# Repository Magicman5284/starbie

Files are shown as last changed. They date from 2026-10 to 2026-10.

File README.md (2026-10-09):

Starbie

Starbie is a virtual pet powered by a Seeed XIAO ESP32-C3, with an OLED display, motion sensing, and temperature/humidity readings. It also works as a Bluetooth macropad.

Features

Virtual pet with Joy, Energy, and Fullness stats

Motion-based interactions and pet activities

Bluetooth shortcuts for Copy, Paste, Cut, Undo, and Screenshot

Switch between pet and macropad modes using D2

Hardware: XIAO ESP32-C3, OLED, MPU6050, DHT11, and six buttons.

Libraries: Adafruit SSD1306, Adafruit GFX, MPU6050, DHT, and a compatible BLE Keyboard library.



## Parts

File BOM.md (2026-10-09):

# Starbie – bill of materials

<!-- Generated by Half Life from project cmuvlfubk01nb01pyzaf8hww4. Edits here are overwritten on the next sync. -->
<!-- Generated: 2026-10-09T00:57:36.305Z -->

> [!NOTE]
> This parts list is mirrored from [Half Life](https://halflife.hackclub.com). Editing it here will not change the platform's copy, and the next sync overwrites this file.

| Week | Tier | Parts funding |
| --- | --- | --- |
| Week 1 | Tier 1 | $30.00 |

| Part | What it's for | Qty | Unit | Total | Vendor |
| --- | --- | --- | --- | --- | --- |
| [PCB](https://cart.jlcpcb.com/quote) | where components are mounted | 1 | $11.19 | $11.19 | [JLCPCB](https://cart.jlcpcb.com/quote) |
| [Keyboard switches](https://www.aliexpress.us/item/3256809144133324.html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) | button inputs | 1 | $3.80 | $3.80 | [Aliexpress](https://www.aliexpress.us/item/3256809144133324.html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) |
| [Keycaps](https://www.aliexpress.us/item/3256812392832257.html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) | to cover the switches | 1 | $2.50 | $2.50 | [Aliexpress](https://www.aliexpress.us/item/3256812392832257.html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) |
| [DHT11](https://www.aliexpress.us/item/3256808632582299.html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) | environmental sensing | 1 | $1.89 | $1.89 | [Aliexpress](https://www.aliexpress.us/item/3256808632582299.html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) |
| [MPU6050](https://www.aliexpress.us/item/3256809871479525.html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) | Accelerometer & Gyroscope | 1 | $2.10 | $2.10 | [aliexpress](https://www.aliexpress.us/item/3256809871479525.html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) |
| [OLED screen](https://www.aliexpress.us/item/3256804169233174.html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) | to display the starby | 1 | $2.21 | $2.21 | [aliexpress](https://www.aliexpress.us/item/3256804169233174.html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) |
| [XIAO ESP32-C3](https://www.aliexpress.us/item/3256809899117724.html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) | to run the program | 1 | $8.83 | $8.83 | [Aliexpress](https://www.aliexpress.us/item/3256809899117724.html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) |
| **Parts subtotal** | — | — | — | **$32.52** | — |
| **Tax & shipping** | — | — | — | **$0.00** | — |
| **Total** | — | — | — | **$32.52** | — |

**$2.52 over the tier's funding.** Every tier gives a fixed amount for parts, so this needs cutting back or a higher tier.

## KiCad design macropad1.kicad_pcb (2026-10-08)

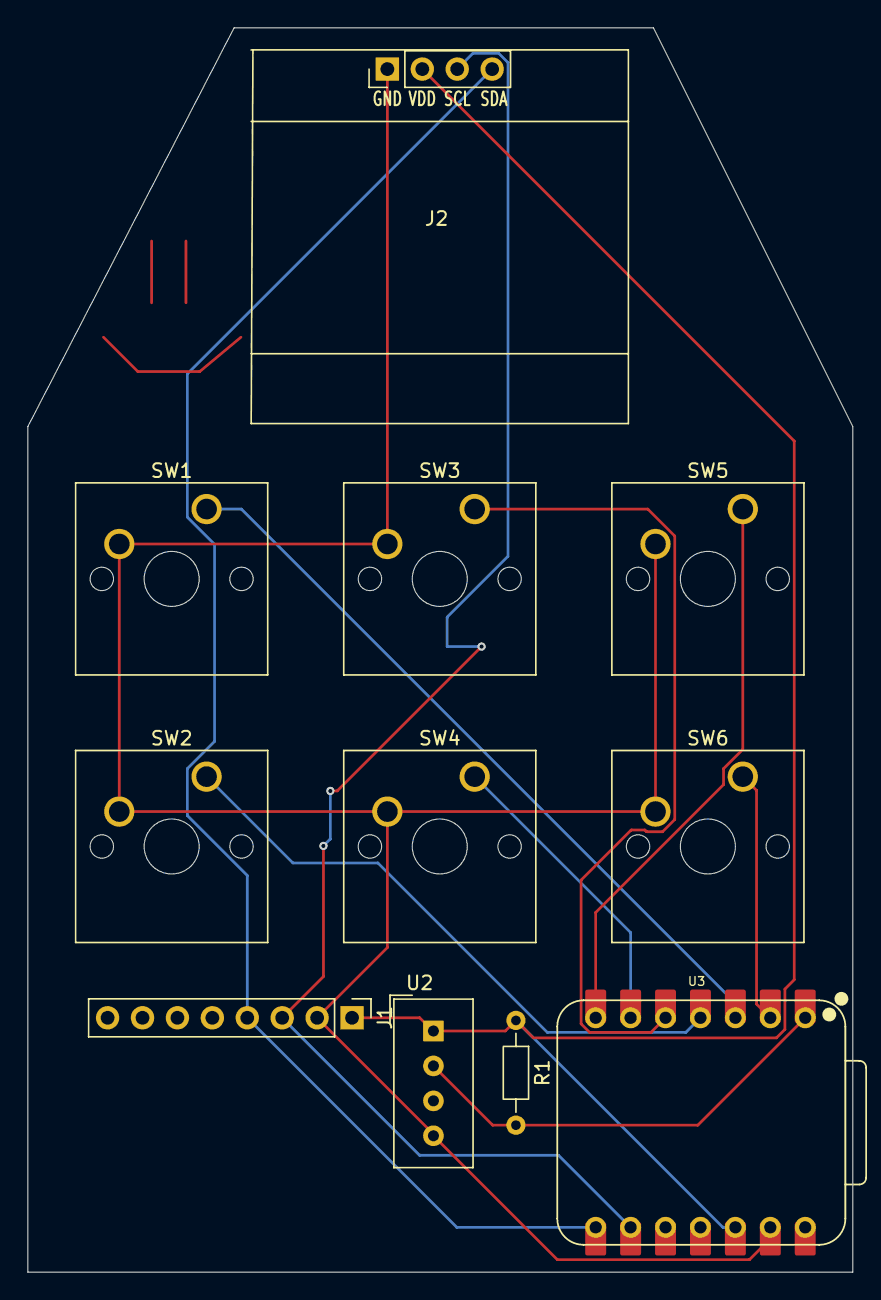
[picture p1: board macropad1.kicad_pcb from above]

Board: 2 copper layers, 60.0 x 90.5 mm, 11 parts (0 on the bottom side), 11 nets.

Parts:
J1: Conn_01x08_Pin; PinHeader_1x08_P2.54mm_Vertical
J2: Conn_01x04_Pin; Display_128x64_096_I2C
R1: 10k; R_Axial_DIN0204_L3.6mm_D1.6mm_P7.62mm_Horizontal
SW1, SW2, SW3, SW4, SW5, SW6: SW_Push; SW_Cherry_MX_1.00u_PCB
U2: DHT11; Aosong_DHT11_5.5x12.0_P2.54mm
U3: XIAO-Add-On; XIAO-ESP32-C3-DIP

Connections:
+3.3V: J1.1, J2.2, R1.1, U2.1 (VDD), U3.12 (3V3_OUT)
/DHT11 DATA: R1.2, U2.2 (DATA), U3.1 (D0)
/GPIO1: SW6.1, U3.2 (D1)
/GPIO2: SW1.1, U3.3 (D2)
/GPIO3: SW2.1, U3.4 (D3)
/GPIO4: SW3.1, U3.5 (D4)
/GPIO5: SW4.1, U3.6 (D5)
/GPIO6: SW5.1, U3.7 (D6)
/SCL: J1.3, J2.3, U3.9 (D8)
/SDA: J1.4, J2.4, U3.8 (D7)
GND: J1.2, J2.1, SW1.2, SW2.2, SW3.2, SW4.2, SW5.2, SW6.2, U2.4 (GND), U3.13 (GND)

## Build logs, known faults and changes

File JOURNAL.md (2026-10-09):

# Starbie – devlog

<!-- Generated by Half Life from project cmuvlfubk01nb01pyzaf8hww4. Edits here are overwritten on the next sync. -->
<!-- Generated: 2026-10-09T01:02:13.699Z -->

> [!NOTE]
> This devlog is mirrored from [Half Life](https://halflife.hackclub.com). Editing it here will not change the platform's copy, and the next sync overwrites this file.

> A tiny motion-controlled digital pet, basically a desktop Tamagotchi. Totally not a Starboy.

| Week | Tier | Hours logged | Entries |
| --- | --- | --- | --- |
| Week 1 | Tier 1 | 12.15h | 5 |

## Contents

1. [2026-10-05 – Work session](#2026-10-05-work-session)
2. [2026-10-06 – Work session](#2026-10-06-work-session)
3. [2026-10-06 – I just finished up designing my PCB and exported the files. It took me way longer than it should have to figure out how to add an image on to the PCB, but I eventually figured it out. After that, I ex](#2026-10-06-i-just-finished-up-designing-my-pcb-and-exported-)
4. [2026-10-08 – In this session I completely redesigned my PCB. I created it more like a macro pad with six buttons instead of the 2 that were in the first one I designed. This was a bit easier than the first time be](#2026-10-08-in-this-session-i-completely-redesigned-my-pcb-i-)
5. [2026-10-08 – This session I did a lot of work in the Arduino ide trying to alter the code for starbie. I tried to make it so that I can toggle it between it acting as a pet and acting as a macropad. In the future,](#2026-10-08-this-session-i-did-a-lot-of-work-in-the-arduino-i)

## Design

### 2026-10-05 – Work session

**0.73h**

[Timelapse](https://lookout.hackclub.com/api/media/c5e8a572-05f9-4baf-ba6c-8380ce65a804/video.mp4)

### 2026-10-06 – Work session

**1.92h**

[Timelapse](https://lookout.hackclub.com/api/media/7532431c-2f96-4bbc-b52b-e5117d1896b4/video.mp4)

### 2026-10-06 – I just finished up designing my PCB and exported the files. It took me way longer than it should have to figure out how to add an image on to the PCB, but I eventually figured it out. After that, I ex

**1h**

I just finished up designing my PCB and exported the files. It took me way longer than it should have to figure out how to add an image on to the PCB, but I eventually figured it out. After that, I exported all of the design and manufacturing files and put them in my project's GitHub. Now I just need to work on the firmware. I am currently considering redesigning the project to have more buttons.





### 2026-10-08 – In this session I completely redesigned my PCB. I created it more like a macro pad with six buttons instead of the 2 that were in the first one I designed. This was a bit easier than the first time be

**5h**

In this session I completely redesigned my PCB. I created it more like a macro pad with six buttons instead of the 2 that were in the first one I designed. This was a bit easier than the first time because I already had a decent idea of what I was doing, but I still had a few hiccups that ended up taking a while to resolve. Now I need to shift my focus from hardware to software and creating the Bill of materials.











### 2026-10-08 – This session I did a lot of work in the Arduino ide trying to alter the code for starbie. I tried to make it so that I can toggle it between it acting as a pet and acting as a macropad. In the future,

**3.5h**

This session I did a lot of work in the Arduino ide trying to alter the code for starbie. I tried to make it so that I can toggle it between it acting as a pet and acting as a macropad. In the future, I think it would be great to have these functions seamlessly integrated so that the pad can interact and react with the macropad.

I also spent some time in the github, adding files and writing the ReadMe. After this I worked on the Bill of materials.









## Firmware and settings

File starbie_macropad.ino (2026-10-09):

/*
  STARBIE + BLUETOOTH MACROPAD
  Board: Seeed XIAO ESP32-C3

  D0 = DHT11 data
  D1 = Button 1
  D2 = Mode toggle
  D3 = Button 3
  D4 = Button 4
  D5 = Button 5
  D6 = Button 6
  D7 = OLED SDA
  D8 = OLED SCL

  Buttons connect their GPIO pin to GND when pressed.

  STARBIE MODE:
    D1 = Open/confirm tilt menu
    D2 = Switch to Macropad mode
    D3 = Show/hide stats
    D4 = Nap
    D5 = Play
    D6 = Feed

  MACROPAD MODE (Windows):
    D1 = Copy
    D2 = Return to Starbie mode
    D3 = Paste
    D4 = Cut
    D5 = Undo
    D6 = Screenshot (Win + Shift + S)
*/

#define USE_NIMBLE
#include <Wire.h>
#include <Adafruit_GFX.h>
#include <Adafruit_SSD1306.h>
#include <Adafruit_MPU6050.h>
#include <Adafruit_Sensor.h>
#include <DHT.h>
#include <Preferences.h>
#include <BleKeyboard.h>
#include <math.h>

// -------------------- PIN SETTINGS --------------------

const int SDA_PIN = 20;       // XIAO D7
const int SCL_PIN = 8;        // XIAO D8
const int DHT_PIN = 2;        // XIAO D0

const int BUTTON_D1 = 3;
const int BUTTON_D2 = 4;
const int BUTTON_D3 = 5;
const int BUTTON_D4 = 6;
const int BUTTON_D5 = 7;
const int BUTTON_D6 = 21;

const int BUTTON_PINS[6] = {
  BUTTON_D1, BUTTON_D2, BUTTON_D3,
  BUTTON_D4, BUTTON_D5, BUTTON_D6
};

const uint8_t OLED_ADDRESS = 0x3C;
const uint8_t MPU_ADDRESS = 0x68;

const bool USE_DHT11 = true;
const bool RESET_SAVED_PET_ON_BOOT = false;

// -------------------- DEVICES --------------------

const int SCREEN_WIDTH = 128;
const int SCREEN_HEIGHT = 64;

Adafruit_SSD1306 display(
  SCREEN_WIDTH, SCREEN_HEIGHT, &Wire, -1
);

Adafruit_MPU6050 mpu;
DHT dht(DHT_PIN, DHT11);
Preferences preferences;

BleKeyboard bleKeyboard(
  "Starbie Macropad", "Starbie", 100
);

// -------------------- PET SETTINGS --------------------

const int PET_WIDTH = 32;
const int PET_HEIGHT = 32;

const int STARTING_JOY = 70;
const int STARTING_ENERGY = 75;
const int STARTING_FULLNESS = 65;

const uint32_t WALK_PIXEL_MS = 70;
const uint32_t PRE_JUMP_MS = 230;
const uint32_t JUMP_MS = 430;
const int JUMP_HEIGHT = 16;

const uint32_t NAP_DURATION_MS = 48000;
const uint32_t HEART_DURATION_MS = 1600;
const uint32_t PLAY_LAP_MS = 800;
const int PLAY_LAP_COUNT = 2;

const uint32_t SHAKE_COOLDOWN_MS = 650;
const float SHAKE_THRESHOLD = 7.0f;
const float GRAVITY = 9.80665f;

const float MENU_TILT_LIMIT = 6.0f;
const float MENU_DEADZONE = 0.8f;
const float MENU_X_DIRECTION = 1.0f;
const float MENU_Y_DIRECTION = -1.0f;
const bool SWAP_MPU_AXES = false;

const uint32_t BUTTON_DEBOUNCE_MS = 30;
const uint32_t MPU_INTERVAL_MS = 30;
const uint32_t DHT_INTERVAL_MS = 2200;

// -------------------- PET DATA --------------------

struct PetState {
  int joy;
  int energy;
  int fullness;
};

PetState pet = {
  STARTING_JOY, STARTING_ENERGY, STARTING_FULLNESS
};

struct ButtonState {
  bool stableState;
  bool lastRawState;
  uint32_t lastChangedAt;
};

ButtonState buttons[6];

enum DeviceMode {
  STARBIE_MODE,
  MACROPAD_MODE
};

enum ScreenView {
  PET_VIEW,
  MENU_VIEW,
  STATS_VIEW
};

DeviceMode currentMode = STARBIE_MODE;
ScreenView currentView = PET_VIEW;

bool mpuFound = false;
bool dhtFound = false;

float accelX = 0;
float accelY = 0;
float accelZ = GRAVITY;

float temperatureC = NAN;
float humidity = NAN;

float menuBallX = 64;
float menuBallY = 32;

float menuCenterX = 0;
float menuCenterY = 0;

int selectedMenuItem = -1;
int nappingPetX = 0;

uint32_t lastMpuReadAt = 0;
uint32_t lastDhtReadAt = 0;
uint32_t lastShakeAt = 0;

uint32_t shakeAnimationEndsAt = 0;
uint32_t jumpStartedAt = 0;
uint32_t nappingUntil = 0;
uint32_t heartsUntil = 0;
uint32_t playStartedAt = 0;

// -------------------- PET SPRITE --------------------

const uint8_t PROGMEM PET_SPRITE[] = {
  0x00,0x00,0x00,0x00,
  0x00,0x00,0x00,0x00,
  0x00,0x00,0x00,0x00,
  0x00,0x00,0x00,0x00,
  0x00,0x00,0x00,0x00,
  0x00,0x00,0x00,0x00,
  0x00,0x70,0x0a,0x00,
  0x00,0xf8,0x1f,0x00,
  0x00,0x8c,0x3f,0x80,
  0x00,0x43,0xff,0x00,
  0x00,0x43,0xff,0x00,
  0x00,0x30,0x7e,0x00,
  0x00,0x98,0x01,0x00,
  0x01,0x98,0x01,0x80,
  0x03,0x00,0x10,0xc0,
  0x03,0x04,0x00,0xc0,
  0x01,0x8b,0x01,0x80,
  0x01,0xcb,0x03,0x80,
  0x03,0xc0,0x03,0xc0,
  0x03,0xc0,0x03,0xc0,
  0x01,0xc0,0x03,0x80,
  0x01,0x80,0x01,0x80,
  0x00,0x60,0x06,0x00,
  0x00,0x3f,0xfc,0x00,
  0x00,0x7f,0xfe,0x00,
  0x00,0x70,0x0e,0x00,
  0x00,0x00,0x00,0x00,
  0x00,0x00,0x00,0x00,
  0x00,0x00,0x00,0x00,
  0x00,0x00,0x00,0x00,
  0x00,0x00,0x00,0x00,
  0x00,0x00,0x00,0x00
};

// -------------------- MENU ACTIONS --------------------

enum PetReaction {
  NAP_REACTION,
  RUN_REACTION,
  JUMP_REACTION,
  HEART_REACTION
};

struct MenuItem {
  const char *label;
  int joy;
  int energy;
  int fullness;
  PetReaction reaction;
};

const MenuItem MENU_ITEMS[] = {
  {"NAP",  1, 18, -4, NAP_REACTION},
  {"PLAY", 12, -9, -5, RUN_REACTION},
  {"FEED", 3, 2, 18, JUMP_REACTION},
  {"PET",  7, 0, 0, HEART_REACTION}
};

const int MENU_X[] = {64, 108, 64, 20};
const int MENU_Y[] = {12, 32, 53, 32};

// -------------------- GENERAL HELPERS --------------------

int clampStat(int value) {
  return constrain(value, 0, 100);
}

void changePet(int joy, int energy, int fullness) {
  pet.joy = clampStat(pet.joy + joy);
  pet.energy = clampStat(pet.energy + energy);
  pet.fullness = clampStat(pet.fullness + fullness);
}

void savePet() {
  preferences.putInt("joy", pet.joy);
  preferences.putInt("energy", pet.energy);
  preferences.putInt("full", pet.fullness);
}

void loadPet() {
  preferences.begin("starbie", false);

  if (RESET_SAVED_PET_ON_BOOT) {
    preferences.clear();
  }

  pet.joy = preferences.getInt("joy", STARTING_JOY);
  pet.energy = preferences.getInt("energy", STARTING_ENERGY);
  pet.fullness = preferences.getInt("full", STARTING_FULLNESS);
}

bool wasPressed(int index) {
  bool raw = digitalRead(BUTTON_PINS[index]);
  uint32_t now = millis();

  if (raw != buttons[index].lastRawState) {
    buttons[index].lastRawState = raw;
    buttons[index].lastChangedAt = now;
  }

  if (raw != buttons[index].stableState &&
      now - buttons[index].lastChangedAt >=
      BUTTON_DEBOUNCE_MS) {
    buttons[index].stableState = raw;
    return buttons[index].stableState == LOW;
  }

  return false;
}

bool isNapping() {
  return nappingUntil != 0 && millis() < nappingUntil;
}

bool isPlaying() {
  return playStartedAt != 0 &&
         millis() - playStartedAt <
         PLAY_LAP_MS * PLAY_LAP_COUNT;
}

int walkingX(uint32_t now) {
  const int farthest = SCREEN_WIDTH - PET_WIDTH;
  const uint32_t roundTrip = farthest * 2UL;
  const uint32_t step = (now / WALK_PIXEL_MS) % roundTrip;

  return step <= farthest ? step : roundTrip - step;
}

int runningX(uint32_t now) {
  const int farthest = SCREEN_WIDTH - PET_WIDTH;
  float progress = float((now - playStartedAt) % PLAY_LAP_MS)
                   / PLAY_LAP_MS;

  if (progress < 0.5f) {
    return int(progress * 2.0f * farthest);
  }

  return int((1.0f - progress) * 2.0f * farthest);
}

// -------------------- SENSOR UPDATES --------------------

void updateMPU() {
  if (!mpuFound ||
      millis() - lastMpuReadAt < MPU_INTERVAL_MS) {
    return;
  }

  lastMpuReadAt = millis();

  sensors_event_t acceleration;
  sensors_event_t gyro;
  sensors_event_t sensorTemperature;

  mpu.getEvent(
    &acceleration, &gyro, &sensorTemperature
  );

  accelX = acceleration.acceleration.x;
  accelY = acceleration.acceleration.y;
  accelZ = acceleration.acceleration.z;
}

void updateDHT() {
  if (!dhtFound ||
      millis() - lastDhtReadAt < DHT_INTERVAL_MS) {
    return;
  }

  lastDhtReadAt = millis();

  float newHumidity = dht.readHumidity();
  float newTemperature = dht.readTemperature();

  if (!isnan(newHumidity)) {
    humidity = newHumidity;
  }

  if (!isnan(newTemperature)) {
    temperatureC = newTemperature;
  }
}

// -------------------- PET ACTIONS --------------------

void doNap() {
  uint32_t now = millis();

  nappingPetX = walkingX(now);
  nappingUntil = now + NAP_DURATION_MS;

  jumpStartedAt = 0;
  playStartedAt = 0;
  heartsUntil = 0;

  changePet(1, 18, -4);
  savePet();
}

void doPlay() {
  playStartedAt = millis();
  jumpStartedAt = 0;
  nappingUntil = 0;
  heartsUntil = playStartedAt + PLAY_LAP_MS * PLAY_LAP_COUNT;

  changePet(12, -9, -5);
  savePet();
}

void doFeed() {
  uint32_t now = millis();

  nappingUntil = 0;
  playStartedAt = 0;
  jumpStartedAt = now;
  heartsUntil = 0;

  changePet(3, 2, 18);
  savePet();
}

void doPet() {
  uint32_t now = millis();

  nappingUntil = 0;
  playStartedAt = 0;
  jumpStartedAt = now;
  heartsUntil = now + HEART_DURATION_MS;

  changePet(7, 0, 0);
  savePet();
}

void updatePetTimers() {
  uint32_t now = millis();

  if (nappingUntil != 0 && now >= nappingUntil) {
    nappingUntil = 0;
  }

  if (playStartedAt != 0 && !isPlaying()) {
    playStartedAt = 0;
  }

  if (jumpStartedAt != 0 &&
      now - jumpStartedAt >= PRE_JUMP_MS + JUMP_MS) {
    jumpStartedAt = 0;
  }
}

void checkForShake() {
  if (!mpuFound || currentView != PET_VIEW) {
    return;
  }

  float magnitude = sqrtf(
    accelX * accelX +
    accelY * accelY +
    accelZ * accelZ
  );

  uint32_t now = millis();

  if (fabsf(magnitude - GRAVITY) >= SHAKE_THRESHOLD &&
      now - lastShakeAt >= SHAKE_COOLDOWN_MS) {
    lastShakeAt = now;
    nappingUntil = 0;
    shakeAnimationEndsAt = now + 350;

    changePet(5, -2, -1);
    savePet();
  }
}

// -------------------- RADIAL MENU --------------------

void openMenu() {
  currentView = MENU_VIEW;
  selectedMenuItem = -1;

  menuBallX = 64;
  menuBallY = 32;

  menuCenterX = accelX;
  menuCenterY = accelY;
}

void updateMenuBall() {
  if (!mpuFound) {
    selectedMenuItem = -1;
    return;
  }

  float xTilt = accelX - menuCenterX;
  float yTilt = accelY - menuCenterY;

  if (SWAP_MPU_AXES) {
    float temp = xTilt;
    xTilt = yTilt;
    yTilt = temp;
  }

  xTilt = constrain(
    xTilt * MENU_X_DIRECTION,
    -MENU_TILT_LIMIT, MENU_TILT_LIMIT
  );

  yTilt = constrain(
    yTilt * MENU_Y_DIRECTION,
    -MENU_TILT_LIMIT, MENU_TILT_LIMIT
  );

  float targetX = 64 + (xTilt / MENU_TILT_LIMIT) * 37;
  float targetY = 32 + (yTilt / MENU_TILT_LIMIT) * 22;

  menuBallX += (targetX - menuBallX) * 0.20f;
  menuBallY += (targetY - menuBallY) * 0.20f;

  if (fabsf(xTilt) < MENU_DEADZONE &&
      fabsf(yTilt) < MENU_DEADZONE) {
    selectedMenuItem = -1;
  } else if (fabsf(xTilt) > fabsf(yTilt)) {
    selectedMenuItem = xTilt > 0 ? 1 : 3;
  } else {
    selectedMenuItem = yTilt > 0 ? 2 : 0;
  }
}

void chooseMenuItem() {
  if (selectedMenuItem < 0) {
    return;
  }

  const MenuItem &item = MENU_ITEMS[selectedMenuItem];

  if (item.reaction == NAP_REACTION) {
    doNap();
  } else if (item.reaction == RUN_REACTION) {
    doPlay();
  } else if (item.reaction == JUMP_REACTION) {
    doFeed();
  } else {
    doPet();
  }

  currentView = PET_VIEW;
}

// -------------------- BLUETOOTH MACROPAD --------------------

void sendShortcut(uint8_t modifier, char key) {
  if (!bleKeyboard.isConnected()) {
    Serial.println("Macropad: Bluetooth not connected.");
    return;
  }

  bleKeyboard.press(modifier);
  bleKeyboard.press(key);

  delay(40);
  bleKeyboard.releaseAll();
  delay(30);
}

void sendScreenshotShortcut() {
  if (!bleKeyboard.isConnected()) {
    Serial.println("Macropad: Bluetooth not connected.");
    return;
  }

  // Windows + Shift + S
  bleKeyboard.press(KEY_LEFT_GUI);
  bleKeyboard.press(KEY_LEFT_SHIFT);
  bleKeyboard.press('s');

  delay(60);
  bleKeyboard.releaseAll();
  delay(30);
}

void handleMacropadButtons() {
  if (wasPressed(0)) {
    sendShortcut(KEY_LEFT_CTRL, 'c');  // D1: Copy
  }

  if (wasPressed(2)) {
    sendShortcut(KEY_LEFT_CTRL, 'v');  // D3: Paste
  }

  if (wasPressed(3)) {
    sendShortcut(KEY_LEFT_CTRL, 'x');  // D4: Cut
  }

  if (wasPressed(4)) {
    sendShortcut(KEY_LEFT_CTRL, 'z');  // D5: Undo
  }

  if (wasPressed(5)) {
    sendScreenshotShortcut();          // D6: Screenshot
  }
}

// -------------------- MODE AND BUTTON HANDLING --------------------

void toggleMode() {
  if (currentMode == STARBIE_MODE) {
    currentMode = MACROPAD_MODE;
    currentView = PET_VIEW;
    Serial.println("Mode: MACROPAD");
  } else {
    currentMode = STARBIE_MODE;
    currentView = PET_VIEW;
    Serial.println("Mode: STARBIE");
  }
}

void handleButtons() {
  // D2 always changes modes, regardless of the current mode.
  if (wasPressed(1)) {
    toggleMode();
    return;
  }

  if (currentMode == MACROPAD_MODE) {
    handleMacropadButtons();
    return;
  }

  // Starbie mode:
  if (wasPressed(0)) {
    if (currentView == MENU_VIEW) {
      chooseMenuItem();
    } else {
      openMenu();
    }
  }

  if (wasPressed(2)) {
    currentView = currentView == STATS_VIEW
                    ? PET_VIEW
                    : STATS_VIEW;
  }

  // Three extra direct-action buttons.
  if (wasPressed(3)) {
    doNap();
    currentView = PET_VIEW;
  }

  if (wasPressed(4)) {
    doPlay();
    currentView = PET_VIEW;
  }

  if (wasPressed(5)) {
    doFeed();
    currentView = PET_VIEW;
  }
}

// -------------------- DISPLAY DRAWING --------------------

void drawHeart(int x, int y) {
  display.fillRect(x - 2, y, 2, 2, SSD1306_WHITE);
  display.fillRect(x + 1, y, 2, 2, SSD1306_WHITE);
  display.fillRect(x - 3, y + 2, 7, 2, SSD1306_WHITE);
  display.fillRect(x - 2, y + 4, 5, 1, SSD1306_WHITE);
  display.fillRect(x - 1, y + 5, 3, 1, SSD1306_WHITE);
  display.drawPixel(x, y + 6, SSD1306_WHITE);
}

void drawPet() {
  display.clearDisplay();

  uint32_t now = millis();

  int petX = isNapping() ? nappingPetX : walkingX(now);

  if (isPlaying()) {
    petX = runningX(now);
  }

  int petY = SCREEN_HEIGHT - PET_HEIGHT;

  if (now < shakeAnimationEndsAt) {
    petX += int(sinf(now / 18.0f) * 3.0f);
  }

  if (!isNapping() && jumpStartedAt != 0) {
    uint32_t age = now - jumpStartedAt;

    if (age < PRE_JUMP_MS) {
      petX += int(sinf(now / 16.0f) * 3.0f);
    } else if (age < PRE_JUMP_MS + JUMP_MS) {
      float progress = float(age - PRE_JUMP_MS) / JUMP_MS;
      petY -= int(sinf(progress * PI) * JUMP_HEIGHT);
    }
  }

  petX = constrain(petX, 0, SCREEN_WIDTH - PET_WIDTH);

  display.drawBitmap(
    petX, petY, PET_SPRITE,
    PET_WIDTH, PET_HEIGHT, SSD1306_WHITE
  );

  if (isNapping()) {
    int rise = (now / 300UL) % 15UL;

    display.setTextSize(1);
    display.setTextColor(SSD1306_WHITE);
    display.setCursor(petX + 23, petY - 2 - rise);
    display.print("z");
    display.setCursor(petX + 28, petY - 8 - rise / 2);
    display.print("z");
  }

  if (now < heartsUntil) {
    float progress = 1.0f -
      float(heartsUntil - now) / HEART_DURATION_MS;

    int rise = int(progress * 18.0f);
    drawHeart(petX + 10, petY - 3 - rise);
    drawHeart(petX + 22, petY - 9 - rise / 2);
  }
}

void drawMenuItem(int item) {
  const int boxWidth = 33;
  const int boxHeight = 12;

  int x = MENU_X[item] - boxWidth / 2;
  int y = MENU_Y[item] - boxHeight / 2;

  bool selected = item == selectedMenuItem;

  if (selected) {
    display.fillRoundRect(
      x, y, boxWidth, boxHeight, 3, SSD1306_WHITE
    );
    display.setTextColor(SSD1306_BLACK);
  } else {
    display.drawRoundRect(
      x, y, boxWidth, boxHeight, 3, SSD1306_WHITE
    );
    display.setTextColor(SSD1306_WHITE);
  }

  display.setTextSize(1);
  display.setCursor(
    MENU_X[item] - strlen(MENU_ITEMS[item].label) * 3,
    MENU_Y[item] - 3
  );

  display.print(MENU_ITEMS[item].label);
  display.setTextColor(SSD1306_WHITE);
}

void drawMenu() {
  display.clearDisplay();

  display.drawLine(0, 0, 127, 63, SSD1306_WHITE);
  display.drawLine(0, 63, 127, 0, SSD1306_WHITE);

  for (int i = 0; i < 4; i++) {
    drawMenuItem(i);
  }

  display.drawCircle(64, 32, 11, SSD1306_WHITE);
  display.fillCircle(
    int(menuBallX), int(menuBallY), 4, SSD1306_WHITE
  );
}

void drawStatBar(int y, const char *label, int value) {
  display.setTextSize(1);
  display.setTextColor(SSD1306_WHITE);
  display.setCursor(4, y);
  display.print(label);

  display.drawRect(48, y, 57, 8, SSD1306_WHITE);

  display.fillRect(
    49, y + 1, map(value, 0, 100, 0, 55),
    6, SSD1306_WHITE
  );

  display.setCursor(109, y);
  display.print(value);
}

void drawStats() {
  display.clearDisplay();

  drawStatBar(5, "JOY", pet.joy);
  drawStatBar(20, "ENERGY", pet.energy);
  drawStatBar(35, "FULL", pet.fullness);

  display.setTextSize(1);
  display.setTextColor(SSD1306_WHITE);
  display.setCursor(4, 53);

  if (!isnan(temperatureC)) {
    display.print("T ");
    display.print(int(temperatureC));
    display.print("C");
  } else {
    display.print("T --");
  }

  display.setCursor(76, 53);

  if (!isnan(humidity)) {
    display.print("H ");
    display.print(int(humidity));
    display.print("%");
  } else {
    display.print("H --");
  }
}

void drawMacropad() {
  display.clearDisplay();
  display.setTextColor(SSD1306_WHITE);
  display.setTextSize(1);

  display.setCursor(0, 0);
  display.println("MACROPAD");

  display.setCursor(0, 12);
  display.println("D1: Copy   D3: Paste");

  display.setCursor(0, 24);
  display.println("D4: Cut    D5: Undo");

  display.setCursor(0, 36);
  display.println("D6: Screenshot");

  display.setCursor(0, 50);

  if (bleKeyboard.isConnected()) {
    display.println("Bluetooth: Connected");
  } else {
    display.println("Bluetooth: Waiting...");
  }
}

void drawCurrentView() {
  if (currentMode == MACROPAD_MODE) {
    drawMacropad();
  } else if (currentView == MENU_VIEW) {
    drawMenu();
  } else if (currentView == STATS_VIEW) {
    drawStats();
  } else {
    drawPet();
  }

  display.display();
}

// -------------------- SETUP --------------------

void setup() {
  Serial.begin(115200);

  Wire.begin(SDA_PIN, SCL_PIN);

  for (int i = 0; i < 6; i++) {
    pinMode(BUTTON_PINS[i], INPUT_PULLUP);

    buttons[i].stableState = digitalRead(BUTTON_PINS[i]);
    buttons[i].lastRawState = buttons[i].stableState;
    buttons[i].lastChangedAt = millis();
  }

  loadPet();

  if (!display.begin(
        SSD1306_SWITCHCAPVCC, OLED_ADDRESS)) {
    Serial.println("OLED not found. Check SDA/SCL and address.");

    while (true) {
      delay(10);
    }
  }

  mpuFound = mpu.begin(MPU_ADDRESS, &Wire);

  if (mpuFound) {
    mpu.setAccelerometerRange(MPU6050_RANGE_8_G);
    mpu.setGyroRange(MPU6050_RANGE_500_DEG);
    mpu.setFilterBandwidth(MPU6050_BAND_21_HZ);
    Serial.println("MPU6050 found.");
  } else {
    Serial.println("MPU6050 not found. Tilt menu unavailable.");
  }

  if (USE_DHT11) {
    dht.begin();
    dhtFound = true;
  }

  bleKeyboard.begin();

  Serial.println("Starbie started.");
  Serial.println("Pair 'Starbie Macropad' over Bluetooth.");

  drawCurrentView();
}

// -------------------- MAIN LOOP --------------------

void loop() {
  updateMPU();
  updateDHT();
  updatePetTimers();

  handleButtons();

  if (currentMode == STARBIE_MODE) {
    if (currentView == MENU_VIEW) {
      updateMenuBall();
    } else {
      checkForShake();
    }
  }

  drawCurrentView();

  delay(16);
}

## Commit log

2026-10-18 Update README with BOM and project features
    Added a BOM section with item details and links for components used in the project.
2026-10-19 added new .zip file
    inculdes .kicad_pro and .kicad_sch files
2026-10-19 Add new screenshot to README
    Added a screenshot of the schematic to README
2026-10-20 Added files
    Added .kicad_pcb, .kicad_prl, .kicad_pro, and .kicad_sch files to main branch
